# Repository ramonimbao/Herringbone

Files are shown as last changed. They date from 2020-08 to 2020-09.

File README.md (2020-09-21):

# Herringbone

### Through-hole 75% Keyboard



### Partslist
 |Count|Part|
 |-|-|
 |1|ATmega32A 40 pin DIP|
 |1|40 pin DIP socket|
 |1|HRO-TYPE-C-M-12|
 |1|500 mA polyfuse|
 |2|6mm momentary push buttons|
 |1|16 MHz quartz crystal|
 |1|10 uF electrolytic capacitor|
 |2|100 nF ceramic disk capacitor|
 |2|22 pF ceramic disk capacitor|
 |2|68 Ω resistor|
 |2|1.5 kΩ resistor|
 |2|5.1 kΩ resistor|
 |2|3.6 V zener diode|
 |84|universal switching diode|

This design may be freely produced, modified, and manufactured for **PERSONAL USE ONLY** and may not be reproduced in physical form for public sale.

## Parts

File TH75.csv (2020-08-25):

Source: | D:\Projects\KiCad\TH75\TH75.sch
Date: | 31 May 2020 2:26:34 PM
Tool: | Eeschema (5.1.6)-1
Generator: | D:\Applications\KiCad5\bin\scripting\plugins/bom_csv_grouped_by_value.py
Component Count: | 209
Individual Components:
Item | Qty | Reference(s) | Value | LibPart | Footprint | Datasheet
 |  | C1 | 22pF | Device:C_Small | Capacitor_THT:C_Disc_D3.0mm_W1.6mm_P2.50mm | ~
 |  | C2 | 22pF | Device:C_Small | Capacitor_THT:C_Disc_D3.0mm_W1.6mm_P2.50mm | ~
 |  | C3 | 100nF | Device:C_Small | Capacitor_THT:C_Disc_D4.3mm_W1.9mm_P5.00mm | ~
 |  | C4 | 100nF | Device:C_Small | Capacitor_THT:C_Disc_D4.3mm_W1.9mm_P5.00mm | ~
 |  | C5 | 10uF | Device:C_Small | Capacitor_THT:CP_Radial_D4.0mm_P1.50mm | ~
 |  | D1 | LED | Device:LED | LED_THT:LED_D3.0mm | ~
 |  | D2 | 3.6V | Device:D_Zener_Small | Diode_THT:D_DO-34_SOD68_P7.62mm_Horizontal | ~
 |  | D3 | 3.6V | Device:D_Zener_Small | Diode_THT:D_DO-34_SOD68_P7.62mm_Horizontal | ~
 |  | D4 | 1N4148 | Device:D_Small | Diode_THT:D_DO-34_SOD68_P7.62mm_Horizontal | ~
 |  | D5 | 1N4148 | Device:D_Small | Diode_THT:D_DO-34_SOD68_P7.62mm_Horizontal | ~
 |  | D6 | 1N4148 | Device:D_Small | Diode_THT:D_DO-34_SOD68_P7.62mm_Horizontal | ~
 |  | D7 | 1N4148 | Device:D_Small | Diode_THT:D_DO-34_SOD68_P7.62mm_Horizontal | ~
 |  | D8 | 1N4148 | Device:D_Small | Diode_THT:D_DO-34_SOD68_P7.62mm_Horizontal | ~
 |  | D9 | 1N4148 | Device:D_Small | Diode_THT:D_DO-34_SOD68_P7.62mm_Horizontal | ~
 |  | D10 | 1N4148 | Device:D_Small | Diode_THT:D_DO-34_SOD68_P7.62mm_Horizontal | ~
 |  | D11 | 1N4148 | Device:D_Small | Diode_THT:D_DO-34_SOD68_P7.62mm_Horizontal | ~
 |  | D12 | 1N4148 | Device:D_Small | Diode_THT:D_DO-34_SOD68_P7.62mm_Horizontal | ~
 |  | D13 | 1N4148 | Device:D_Small | Diode_THT:D_DO-34_SOD68_P7.62mm_Horizontal | ~
 |  | D14 | 1N4148 | Device:D_Small | Diode_THT:D_DO-34_SOD68_P7.62mm_Horizontal | ~
 |  | D15 | 1N4148 | Device:D_Small | Diode_THT:D_DO-34_SOD68_P7.62mm_Horizontal | ~
 |  | D16 | 1N4148 | Device:D_Small | Diode_THT:D_DO-34_SOD68_P7.62mm_Horizontal | ~
 |  | D17 | 1N4148 | Device:D_Small | Diode_THT:D_DO-34_SOD68_P7.62mm_Horizontal | ~
 |  | D18 | 1N4148 | Device:D_Small | Diode_THT:D_DO-34_SOD68_P7.62mm_Horizontal | ~
 |  | D19 | 1N4148 | Device:D_Small | Diode_THT:D_DO-34_SOD68_P7.62mm_Horizontal | ~
 |  | D20 | 1N4148 | Device:D_Small | Diode_THT:D_DO-34_SOD68_P7.62mm_Horizontal | ~
 |  | D21 | 1N4148 | Device:D_Small | Diode_THT:D_DO-34_SOD68_P7.62mm_Horizontal | ~
 |  | D22 | 1N4148 | Device:D_Small | Diode_THT:D_DO-34_SOD68_P7.62mm_Horizontal | ~
 |  | D23 | 1N4148 | Device:D_Small | Diode_THT:D_DO-34_SOD68_P7.62mm_Horizontal | ~
 |  | D24 | 1N4148 | Device:D_Small | Diode_THT:D_DO-34_SOD68_P7.62mm_Horizontal | ~
 |  | D25 | 1N4148 | Device:D_Small | Diode_THT:D_DO-34_SOD68_P7.62mm_Horizontal | ~
 |  | D26 | 1N4148 | Device:D_Small | Diode_THT:D_DO-34_SOD68_P7.62mm_Horizontal | ~
 |  | D27 | 1N4148 | Device:D_Small | Diode_THT:D_DO-34_SOD68_P7.62mm_Horizontal | ~
 |  | D28 | 1N4148 | Device:D_Small | Diode_THT:D_DO-34_SOD68_P7.62mm_Horizontal | ~
 |  | D29 | 1N4148 | Device:D_Small | Diode_THT:D_DO-34_SOD68_P7.62mm_Horizontal | ~
 |  | D30 | 1N4148 | Device:D_Small | Diode_THT:D_DO-34_SOD68_P7.62mm_Horizontal | ~
 |  | D31 | 1N4148 | Device:D_Small | Diode_THT:D_DO-34_SOD68_P7.62mm_Horizontal | ~
 |  | D32 | 1N4148 | Device:D_Small | Diode_THT:D_DO-34_SOD68_P7.62mm_Horizontal | ~
 |  | D33 | 1N4148 | Device:D_Small | Diode_THT:D_DO-34_SOD68_P7.62mm_Horizontal | ~
 |  | D34 | 1N4148 | Device:D_Small | Diode_THT:D_DO-34_SOD68_P7.62mm_Horizontal | ~
 |  | D35 | 1N4148 | Device:D_Small | Diode_THT:D_DO-34_SOD68_P7.62mm_Horizontal | ~
 |  | D36 | 1N4148 | Device:D_Small | Diode_THT:D_DO-34_SOD68_P7.62mm_Horizontal | ~
 |  | D37 | 1N4148 | Device:D_Small | Diode_THT:D_DO-34_SOD68_P7.62mm_Horizontal | ~
 |  | D38 | 1N4148 | Device:D_Small | Diode_THT:D_DO-34_SOD68_P7.62mm_Horizontal | ~
 |  | D39 | 1N4148 | Device:D_Small | Diode_THT:D_DO-34_SOD68_P7.62mm_Horizontal | ~
 |  | D40 | 1N4148 | Device:D_Small | Diode_THT:D_DO-34_SOD68_P7.62mm_Horizontal | ~
 |  | D41 | 1N4148 | Device:D_Small | Diode_THT:D_DO-34_SOD68_P7.62mm_Horizontal | ~
 |  | D42 | 1N4148 | Device:D_Small | Diode_THT:D_DO-34_SOD68_P7.62mm_Horizontal | ~
 |  | D43 | 1N4148 | Device:D_Small | Diode_THT:D_DO-34_SOD68_P7.62mm_Horizontal | ~
 |  | D44 | 1N4148 | Device:D_Small | Diode_THT:D_DO-34_SOD68_P7.62mm_Horizontal | ~
 |  | D45 | 1N4148 | Device:D_Small | Diode_THT:D_DO-34_SOD68_P7.62mm_Horizontal | ~
 |  | D46 | 1N4148 | Device:D_Small | Diode_THT:D_DO-34_SOD68_P7.62mm_Horizontal | ~
 |  | D47 | 1N4148 | Device:D_Small | Diode_THT:D_DO-34_SOD68_P7.62mm_Horizontal | ~
 |  | D48 | 1N4148 | Device:D_Small | Diode_THT:D_DO-34_SOD68_P7.62mm_Horizontal | ~
 |  | D49 | 1N4148 | Device:D_Small | Diode_THT:D_DO-34_SOD68_P7.62mm_Horizontal | ~
 |  | D50 | 1N4148 | Device:D_Small | Diode_THT:D_DO-34_SOD68_P7.62mm_Horizontal | ~
 |  | D51 | 1N4148 | Device:D_Small | Diode_THT:D_DO-34_SOD68_P7.62mm_Horizontal | ~
 |  | D52 | 1N4148 | Device:D_Small | Diode_THT:D_DO-34_SOD68_P7.62mm_Horizontal | ~
 |  | D53 | 1N4148 | Device:D_Small | Diode_THT:D_DO-34_SOD68_P7.62mm_Horizontal | ~
 |  | D54 | 1N4148 | Device:D_Small | Diode_THT:D_DO-34_SOD68_P7.62mm_Horizontal | ~
 |  | D55 | 1N4148 | Device:D_Small | Diode_THT:D_DO-34_SOD68_P7.62mm_Horizontal | ~
 |  | D56 | 1N4148 | Device:D_Small | Diode_THT:D_DO-34_SOD68_P7.62mm_Horizontal | ~
 |  | D57 | 1N4148 | Device:D_Small | Diode_THT:D_DO-34_SOD68_P7.62mm_Horizontal | ~
 |  | D58 | 1N4148 | Device:D_Small | Diode_THT:D_DO-34_SOD68_P7.62mm_Horizontal | ~
 |  | D59 | 1N4148 | Device:D_Small | Diode_THT:D_DO-34_SOD68_P7.62mm_Horizontal | ~
 |  | D60 | 1N4148 | Device:D_Small | Diode_THT:D_DO-34_SOD68_P7.62mm_Horizontal | ~
 |  | D61 | 1N4148 | Device:D_Small | Diode_THT:D_DO-34_SOD68_P7.62mm_Horizontal | ~
 |  | D62 | 1N4148 | Device:D_Small | Diode_THT:D_DO-34_SOD68_P7.62mm_Horizontal | ~
 |  | D63 | 1N4148 | Device:D_Small | Diode_THT:D_DO-34_SOD68_P7.62mm_Horizontal | ~
 |  | D64 | 1N4148 | Device:D_Small | Diode_THT:D_DO-34_SOD68_P7.62mm_Horizontal | ~
 |  | D65 | 1N4148 | Device:D_Small | Diode_THT:D_DO-34_SOD68_P7.62mm_Horizontal | ~
 |  | D66 | 1N4148 | Device:D_Small | Diode_THT:D_DO-34_SOD68_P7.62mm_Horizontal | ~
 |  | D67 | 1N4148 | Device:D_Small | Diode_THT:D_DO-34_SOD68_P7.62mm_Horizontal | ~
 |  | D68 | 1N4148 | Device:D_Small | Diode_THT:D_DO-34_SOD68_P7.62mm_Horizontal | ~
 |  | D69 | 1N4148 | Device:D_Small | Diode_THT:D_DO-34_SOD68_P7.62mm_Horizontal | ~
 |  | D70 | 1N4148 | Device:D_Small | Diode_THT:D_DO-34_SOD68_P7.62mm_Horizontal | ~
 |  | D71 | 1N4148 | Device:D_Small | Diode_THT:D_DO-34_SOD68_P7.62mm_Horizontal | ~
 |  | D72 | 1N4148 | Device:D_Small | Diode_THT:D_DO-34_SOD68_P7.62mm_Horizontal | ~
 |  | D73 | 1N4148 | Device:D_Small | Diode_THT:D_DO-34_SOD68_P7.62mm_Horizontal | ~
 |  | D74 | 1N4148 | Device:D_Small | Diode_THT:D_DO-34_SOD68_P7.62mm_Horizontal | ~
 |  | D75 | 1N4148 | Device:D_Small | Diode_THT:D_DO-34_SOD68_P7.62mm_Horizontal | ~
 |  | D76 | 1N4148 | Device:D_Small | Diode_THT:D_DO-34_SOD68_P7.62mm_Horizontal | ~
 |  | D77 | 1N4148 | Device:D_Small | Diode_THT:D_DO-34_SOD68_P7.62mm_Horizontal | ~
 |  | D78 | 1N4148 | Device:D_Small | Diode_THT:D_DO-34_SOD68_P7.62mm_Horizontal | ~
 |  | D79 | 1N4148 | Device:D_Small | Diode_THT:D_DO-34_SOD68_P7.62mm_Horizontal | ~
 |  | D80 | 1N4148 | Device:D_Small | Diode_THT:D_DO-34_SOD68_P7.62mm_Horizontal | ~
 |  | D81 | 1N4148 | Device:D_Small | Diode_THT:D_DO-34_SOD68_P7.62mm_Horizontal | ~
 |  | D82 | 1N4148 | Device:D_Small | Diode_THT:D_DO-34_SOD68_P7.62mm_Horizontal | ~
 |  | D83 | 1N4148 | Device:D_Small | Diode_THT:D_DO-34_SOD68_P7.62mm_Horizontal | ~
 |  | D84 | 1N4148 | Device:D_Small | Diode_THT:D_DO-34_SOD68_P7.62mm_Horizontal | ~
 |  | D85 | 1N4148 | Device:D_Small | Diode_THT:D_DO-34_SOD68_P7.62mm_Horizontal | ~
 |  | D86 | 1N4148 | Device:D_Small | Diode_THT:D_DO-34_SOD68_P7.62mm_Horizontal | ~
 |  | D87 | 1N4148 | Device:D_Small | Diode_THT:D_DO-34_SOD68_P7.62mm_Horizontal | ~
 |  | F1 | 500mA | Device:Fuse | Capacitor_THT:C_Disc_D5.0mm_W2.5mm_P5.00mm | ~
 |  | G1 | HerringbonePattern | Mechanical:MountingHole | HerringbonePatterns:front-pattern | ~
 |  | H1 | M2 | Mechanical:MountingHole_Pad | MountingHole:MountingHole_2.2mm_M2_Pad_Via | ~
 |  | H2 | M2 | Mechanical:MountingHole_Pad | MountingHole:MountingHole_2.2mm_M2_Pad_Via | ~
 |  | H3 | M2 | Mechanical:MountingHole_Pad | MountingHole:MountingHole_2.2mm_M2_Pad_Via | ~
 |  | H4 | M2 | Mechanical:MountingHole_Pad | MountingHole:MountingHole_2.2mm_M2_Pad_Via | ~
 |  | H5 | M2 | Mechanical:MountingHole_Pad | MountingHole:MountingHole_2.2mm_M2_Pad_Via | ~
 |  | H6 | M2 | Mechanical:MountingHole_Pad | MountingHole:MountingHole_2.2mm_M2_Pad_Via | ~
 |  | H7 | M2 | Mechanical:MountingHole_Pad | MountingHole:MountingHole_2.2mm_M2_Pad_Via | ~
 |  | H8 | M2 | Mechanical:MountingHole_Pad | MountingHole:MountingHole_2.2mm_M2_Pad_Via | ~
 |  | H9 | M2 | Mechanical:MountingHole_Pad | MountingHole:MountingHole_2.2mm_M2_Pad_Via | ~
 |  | H10 | M2 | Mechanical:MountingHole_Pad | MountingHole:MountingHole_2.2mm_M2_Pad_Via | ~
 |  | H11 | LOGO | Mechanical:MountingHole | Ramon:Signature | ~
 |  | H12 | M2 | Mechanical:MountingHole_Pad | MountingHole:MountingHole_2.2mm_M2_Pad_Via | ~
 |  | H13 | M2 | Mechanical:MountingHole_Pad | MountingHole:MountingHole_2.2mm_M2_Pad_Via | ~
 |  | J1 | Conn_02x03_Odd_Even | Connector_Generic:Conn_02x03_Odd_Even | random-keyboard-parts:Reset_Pretty | ~
 |  | J2 | Conn_01x06 | Connector_Generic:Conn_01x06 | Connector_PinSocket_2.54mm:PinSocket_1x06_P2.54mm_Vertical | ~
 |  | MX1 | MX-NoLED | MX_Alps_Hybrid:MX-NoLED | MX_Only:MXOnly-1U-NoLED
 |  | MX2 | MX-NoLED | MX_Alps_Hybrid:MX-NoLED | MX_Only:MXOnly-1U-NoLED
 |  | MX3 | MX-NoLED | MX_Alps_Hybrid:MX-NoLED | MX_Only:MXOnly-1U-NoLED
 |  | MX4 | MX-NoLED | MX_Alps_Hybrid:MX-NoLED | MX_Only:MXOnly-1U-NoLED
 |  | MX5 | MX-NoLED | MX_Alps_Hybrid:MX-NoLED | MX_Only:MXOnly-1U-NoLED
 |  | MX6 | MX-NoLED | MX_Alps_Hybrid:MX-NoLED | MX_Only:MXOnly-1U-NoLED
 |  | MX7 | MX-NoLED | MX_Alps_Hybrid:MX-NoLED | MX_Only:MXOnly-1U-NoLED
 |  | MX8 | MX-NoLED | MX_Alps_Hybrid:MX-NoLED | MX_Only:MXOnly-1U-NoLED
 |  | MX9 | MX-NoLED | MX_Alps_Hybrid:MX-NoLED | MX_Only:MXOnly-1U-NoLED
 |  | MX10 | MX-NoLED | MX_Alps_Hybrid:MX-NoLED | MX_Only:MXOnly-1U-NoLED
 |  | MX11 | MX-NoLED | MX_Alps_Hybrid:MX-NoLED | MX_Only:MXOnly-1U-NoLED
 |  | MX12 | MX-NoLED | MX_Alps_Hybrid:MX-NoLED | MX_Only:MXOnly-1U-NoLED
 |  | MX13 | MX-NoLED | MX_Alps_Hybrid:MX-NoLED | MX_Only:MXOnly-1U-NoLED
 |  | MX14 | MX-NoLED | MX_Alps_Hybrid:MX-NoLED | MX_Only:MXOnly-1U-NoLED
 |  | MX15 | MX-NoLED | MX_Alps_Hybrid:MX-NoLED | MX_Only:MXOnly-1U-NoLED
 |  | MX16 | MX-NoLED | MX_Alps_Hybrid:MX-NoLED | MX_Only:MXOnly-1U-NoLED
 |  | MX17 | MX-NoLED | MX_Alps_Hybrid:MX-NoLED | MX_Only:MXOnly-1U-NoLED
 |  | MX18 | MX-NoLED | MX_Alps_Hybrid:MX-NoLED | MX_Only:MXOnly-1U-NoLED
 |  | MX19 | MX-NoLED | MX_Alps_Hybrid:MX-NoLED | MX_Only:MXOnly-1U-NoLED
 |  | MX20 | MX-NoLED | MX_Alps_Hybrid:MX-NoLED | MX_Only:MXOnly-1U-NoLED
 |  | MX21 | MX-NoLED | MX_Alps_Hybrid:MX-NoLED | MX_Only:MXOnly-1U-NoLED
 |  | MX22 | MX-NoLED | MX_Alps_Hybrid:MX-NoLED | MX_Only:MXOnly-1U-NoLED
 |  | MX23 | MX-NoLED | MX_Alps_Hybrid:MX-NoLED | MX_Only:MXOnly-1U-NoLED
 |  | MX24 | MX-NoLED | MX_Alps_Hybrid:MX-NoLED | MX_Only:MXOnly-1U-NoLED
 |  | MX25 | MX-NoLED | MX_Alps_Hybrid:MX-NoLED | MX_Only:MXOnly-1U-NoLED
 |  | MX26 | MX-NoLED | MX_Alps_Hybrid:MX-NoLED | MX_Only:MXOnly-1U-NoLED
 |  | MX27 | MX-NoLED | MX_Alps_Hybrid:MX-NoLED | MX_Only:MXOnly-1U-NoLED
 |  | MX28 | MX-NoLED | MX_Alps_Hybrid:MX-NoLED | MX_Only:MXOnly-1U-NoLED
 |  | MX29 | MX-NoLED | MX_Alps_Hybrid:MX-NoLED | MX_Only:MXOnly-2U-NoLED
 |  | MX30 | MX-NoLED | MX_Alps_Hybrid:MX-NoLED | MX_Only:MXOnly-1U-NoLED
 |  | MX31 | MX-NoLED | MX_Alps_Hybrid:MX-NoLED | MX_Only:MXOnly-1.5U-NoLED
 |  | MX32 | MX-NoLED | MX_Alps_Hybrid:MX-NoLED | MX_Only:MXOnly-1U-NoLED
 |  | MX33 | MX-NoLED | MX_Alps_Hybrid:MX-NoLED | MX_Only:MXOnly-1U-NoLED
 |  | MX34 | MX-NoLED | MX_Alps_Hybrid:MX-NoLED | MX_Only:MXOnly-1U-NoLED
 |  | MX35 | MX-NoLED | MX_Alps_Hybrid:MX-NoLED | MX_Only:MXOnly-1U-NoLED
 |  | MX36 | MX-NoLED | MX_Alps_Hybrid:MX-NoLED | MX_Only:MXOnly-1U-NoLED
 |  | MX37 | MX-NoLED | MX_Alps_Hybrid:MX-NoLED | MX_Only:MXOnly-1U-NoLED
 |  | MX38 | MX-NoLED | MX_Alps_Hybrid:MX-NoLED | MX_Only:MXOnly-1U-NoLED
 |  | MX39 | MX-NoLED | MX_Alps_Hybrid:MX-NoLED | MX_Only:MXOnly-1U-NoLED
 |  | MX40 | MX-NoLED | MX_Alps_Hybrid:MX-NoLED | MX_Only:MXOnly-1U-NoLED
 |  | MX41 | MX-NoLED | MX_Alps_Hybrid:MX-NoLED | MX_Only:MXOnly-1U-NoLED
 |  | MX42 | MX-NoLED | MX_Alps_Hybrid:MX-NoLED | MX_Only:MXOnly-1U-NoLED
 |  | MX43 | MX-NoLED | MX_Alps_Hybrid:MX-NoLED | MX_Only:MXOnly-1U-NoLED
 |  | MX44 | MX-NoLED | MX_Alps_Hybrid:MX-NoLED | MX_Only:MXOnly-1.5U-NoLED
 |  | MX45 | MX-NoLED | MX_Alps_Hybrid:MX-NoLED | MX_Only:MXOnly-1U-NoLED
 |  | MX46 | MX-NoLED | MX_Alps_Hybrid:MX-NoLED | MX_Only:MXOnly-1.75U-NoLED
 |  | MX47 | MX-NoLED | MX_Alps_Hybrid:MX-NoLED | MX_Only:MXOnly-1U-NoLED
 |  | MX48 | MX-NoLED | MX_Alps_Hybrid:MX-NoLED | MX_Only:MXOnly-1U-NoLED
 |  | MX49 | MX-NoLED | MX_Alps_Hybrid:MX-NoLED | MX_Only:MXOnly-1U-NoLED
 |  | MX50 | MX-NoLED | MX_Alps_Hybrid:MX-NoLED | MX_Only:MXOnly-1U-NoLED
 |  | MX51 | MX-NoLED | MX_Alps_Hybrid:MX-NoLED | MX_Only:MXOnly-1U-NoLED
 |  | MX52 | MX-NoLED | MX_Alps_Hybrid:MX-NoLED | MX_Only:MXOnly-1U-NoLED
 |  | MX53 | MX-NoLED | MX_Alps_Hybrid:MX-NoLED | MX_Only:MXOnly-1U-NoLED
 |  | MX54 | MX-NoLED | MX_Alps_Hybrid:MX-NoLED | MX_Only:MXOnly-1U-NoLED
 |  | MX55 | MX-NoLED | MX_Alps_Hybrid:MX-NoLED | MX_Only:MXOnly-1U-NoLED
 |  | MX56 | MX-NoLED | MX_Alps_Hybrid:MX-NoLED | MX_Only:MXOnly-1U-NoLED
 |  | MX57 | MX-NoLED | MX_Alps_Hybrid:MX-NoLED | MX_Only:MXOnly-1U-NoLED
 |  | MX58 | MX-NoLED | MX_Alps_Hybrid:MX-NoLED | MX_Only:MXOnly-2.25U-NoLED
 |  | MX59 | MX-NoLED | MX_Alps_Hybrid:MX-NoLED | MX_Only:MXOnly-1U-NoLED
 |  | MX60 | MX-NoLED | MX_Alps_Hybrid:MX-NoLED | MX_Only:MXOnly-1.25U-NoLED
 |  | MX61 | MX-NoLED | MX_Alps_Hybrid:MX-NoLED | MX_Only:MXOnly-2.25U-NoLED
 |  | MX62 | MX-NoLED | MX_Alps_Hybrid:MX-NoLED | MX_Only:MXOnly-1U-NoLED
 |  | MX63 | MX-NoLED | MX_Alps_Hybrid:MX-NoLED | MX_Only:MXOnly-1U-NoLED
 |  | MX64 | MX-NoLED | MX_Alps_Hybrid:MX-NoLED | MX_Only:MXOnly-1U-NoLED
 |  | MX65 | MX-NoLED | MX_Alps_Hybrid:MX-NoLED | MX_Only:MXOnly-1U-NoLED
 |  | MX66 | MX-NoLED | MX_Alps_Hybrid:MX-NoLED | MX_Only:MXOnly-1U-NoLED
 |  | MX67 | MX-NoLED | MX_Alps_Hybrid:MX-NoLED | MX_Only:MXOnly-1U-NoLED
 |  | MX68 | MX-NoLED | MX_Alps_Hybrid:MX-NoLED | MX_Only:MXOnly-1U-NoLED
 |  | MX69 | MX-NoLED | MX_Alps_Hybrid:MX-NoLED | MX_Only:MXOnly-1U-NoLED
 |  | MX70 | MX-NoLED | MX_Alps_Hybrid:MX-NoLED | MX_Only:MXOnly-1U-NoLED
 |  | MX71 | MX-NoLED | MX_Alps_Hybrid:MX-NoLED | MX_Only:MXOnly-1U-NoLED
 |  | MX72 | MX-NoLED | MX_Alps_Hybrid:MX-NoLED | MX_Only:MXOnly-1.75U-NoLED
 |  | MX73 | MX-NoLED | MX_Alps_Hybrid:MX-NoLED | MX_Only:MXOnly-1U-NoLED
 |  | MX74 | MX-NoLED | MX_Alps_Hybrid:MX-NoLED | MX_Only:MXOnly-1U-NoLED
 |  | MX75 | MX-NoLED | MX_Alps_Hybrid:MX-NoLED | MX_Only:MXOnly-1.25U-NoLED
 |  | MX76 | MX-NoLED | MX_Alps_Hybrid:MX-NoLED | MX_Only:MXOnly-1.25U-NoLED
 |  | MX77 | MX-NoLED | MX_Alps_Hybrid:MX-NoLED | MX_Only:MXOnly-1.25U-NoLED
 |  | MX78 | MX-NoLED | MX_Alps_Hybrid:MX-NoLED | MX_Only:MXOnly-6.25U-ReversedStabilizers-NoLED
 |  | MX79 | MX-NoLED | MX_Alps_Hybrid:MX-NoLED | MX_Only:MXOnly-1.5U-NoLED
 |  | MX80 | MX-NoLED | MX_Alps_Hybrid:MX-NoLED | MX_Only:MXOnly-1.5U-NoLED
 |  | MX81 | MX-NoLED | MX_Alps_Hybrid:MX-NoLED | MX_Only:MXOnly-1U-NoLED
 |  | MX82 | MX-NoLED | MX_Alps_Hybrid:MX-NoLED | MX_Only:MXOnly-1U-NoLED
 |  | MX83 | MX-NoLED | MX_Alps_Hybrid:MX-NoLED | MX_Only:MXOnly-1U-NoLED
 |  | MX84 | MX-NoLED | MX_Alps_Hybrid:MX-NoLED | MX_Only:MXOnly-1U-NoLED
 |  | MX85 | MX-NoLED | MX_Alps_Hybrid:MX-NoLED | MX_Only:MXOnly-ISO-ROTATED-ReversedStabilizers-NoLED
 |  | MX86 | MX-NoLED | MX_Alps_Hybrid:MX-NoLED | MX_Only:MXOnly-1U-NoLED
 |  | MX87 | MX-NoLED | MX_Alps_Hybrid:MX-NoLED | MX_Only:MXOnly-1U-NoLED
 |  | MX88 | MX-NoLED | MX_Alps_Hybrid:MX-NoLED | MX_Only:MXOnly-1.25U-NoLED
 |  | MX89 | MX-NoLED | MX_Alps_Hybrid:MX-NoLED | MX_Only:MXOnly-1U-NoLED
 |  | R1 | 1.5k | Device:R_Small | Resistor_THT:R_Axial_DIN0204_L3.6mm_D1.6mm_P5.08mm_Horizontal | ~
 |  | R2 | 1.5k | Device:R_Small | Resistor_THT:R_Axial_DIN0204_L3.6mm_D1.6mm_P5.08mm_Horizontal | ~
 |  | R3 | 75 | Device:R_Small | Resistor_THT:R_Axial_DIN0204_L3.6mm_D1.6mm_P5.08mm_Horizontal | ~
 |  | R4 | 75 | Device:R_Small | Resistor_THT:R_Axial_DIN0204_L3.6mm_D1.6mm_P5.08mm_Horizontal | ~
 |  | R5 | 5.1k | Device:R_Small | Resistor_THT:R_Axial_DIN0204_L3.6mm_D1.6mm_P5.08mm_Horizontal | ~
 |  | R6 | 5.1k | Device:R_Small | Resistor_THT:R_Axial_DIN0204_L3.6mm_D1.6mm_P5.08mm_Horizontal | ~
 |  | SW1 | SW_Push | Switch:SW_Push | Button_Switch_THT:SW_PUSH_6mm | ~
 |  | SW2 | SW_Push | Switch:SW_Push | Button_Switch_THT:SW_PUSH_6mm | ~
 |  | U1 | ATmega32A-PU | TH75-rescue:ATmega32A-PU-MCU_Microchip_ATmega | Package_DIP:DIP-40_W15.24mm_Socket | http://ww1.microchip.com/downloads/en/DeviceDoc/atmel-8155-8-bit-microcontroller-avr-atmega32a_datasheet.pdf
 |  | USB1 | HRO-USB-SPACER | Type-C:HRO-USB-SPACER | Type-C:HRO-TYPE-C-31-M-12-USB-Spacer
 |  | Y1 | 16MHz | Device:Crystal | Crystal:Crystal_HC49-4H_Vertical | ~
Collated Components:
Item | Qty | Reference(s) | Value | LibPart | Footprint | Datasheet
1 | 2 | C1, C2 | 22pF | Device:C_Small | Capacitor_THT:C_Disc_D3.0mm_W1.6mm_P2.50mm | ~
2 | 2 | C3, C4 | 100nF | Device:C_Small | Capacitor_THT:C_Disc_D4.3mm_W1.9mm_P5.00mm | ~
3 | 1 | C5 | 10uF | Device:C_Small | Capacitor_THT:CP_Radial_D4.0mm_P1.50mm | ~
4 | 1 | D1 | LED | Device:LED | LED_THT:LED_D3.0mm | ~
5 | 2 | D2, D3 | 3.6V | Device:D_Zener_Small | Diode_THT:D_DO-34_SOD68_P7.62mm_Horizontal | ~
6 | 84 | D4, D5, D6, D7, D8, D9, D10, D11, D12, D13, D14, D15, D16, D17, D18, D19, D20, D21, D22, D23, D24, D25, D26, D27, D28, D29, D30, D31, D32, D33, D34, D35, D36, D37, D38, D39, D40, D41, D42, D43, D44, D45, D46, D47, D48, D49, D50, D51, D52, D53, D54, D55, D56, D57, D58, D59, D60, D61, D62, D63, D64, D65, D66, D67, D68, D69, D70, D71, D72, D73, D74, D75, D76, D77, D78, D79, D80, D81, D82, D83, D84, D85, D86, D87 | 1N4148 | Device:D_Small | Diode_THT:D_DO-34_SOD68_P7.62mm_Horizontal | ~
7 | 1 | F1 | 500mA | Device:Fuse | Capacitor_THT:C_Disc_D5.0mm_W2.5mm_P5.00mm | ~
11 | 1 | J1 | Conn_02x03_Odd_Even | Connector_Generic:Conn_02x03_Odd_Even | random-keyboard-parts:Reset_Pretty | ~
21 | 2 | R1, R2 | 1.5k | Device:R_Small | Resistor_THT:R_Axial_DIN0204_L3.6mm_D1.6mm_P5.08mm_Horizontal | ~
22 | 2 | R3, R4 | 75 | Device:R_Small | Resistor_THT:R_Axial_DIN0204_L3.6mm_D1.6mm_P5.08mm_Horizontal | ~
23 | 2 | R5, R6 | 5.1k | Device:R_Small | Resistor_THT:R_Axial_DIN0204_L3.6mm_D1.6mm_P5.08mm_Horizontal | ~
24 | 2 | SW1, SW2 | SW_Push | Switch:SW_Push | Button_Switch_THT:SW_PUSH_6mm | ~
25 | 1 | U1 | ATmega32A-PU | TH75-rescue:ATmega32A-PU-MCU_Microchip_ATmega | Package_DIP:DIP-40_W15.24mm_Socket | http://ww1.microchip.com/downloads/en/DeviceDoc/atmel-8155-8-bit-microcontroller-avr-atmega32a_datasheet.pdf
26 | 1 | USB1 | HRO-USB-SPACER | Type-C:HRO-USB-SPACER | Type-C:HRO-TYPE-C-31-M-12-USB-Spacer
27 | 1 | Y1 | 16MHz | Device:Crystal | Crystal:Crystal_HC49-4H_Vertical | ~

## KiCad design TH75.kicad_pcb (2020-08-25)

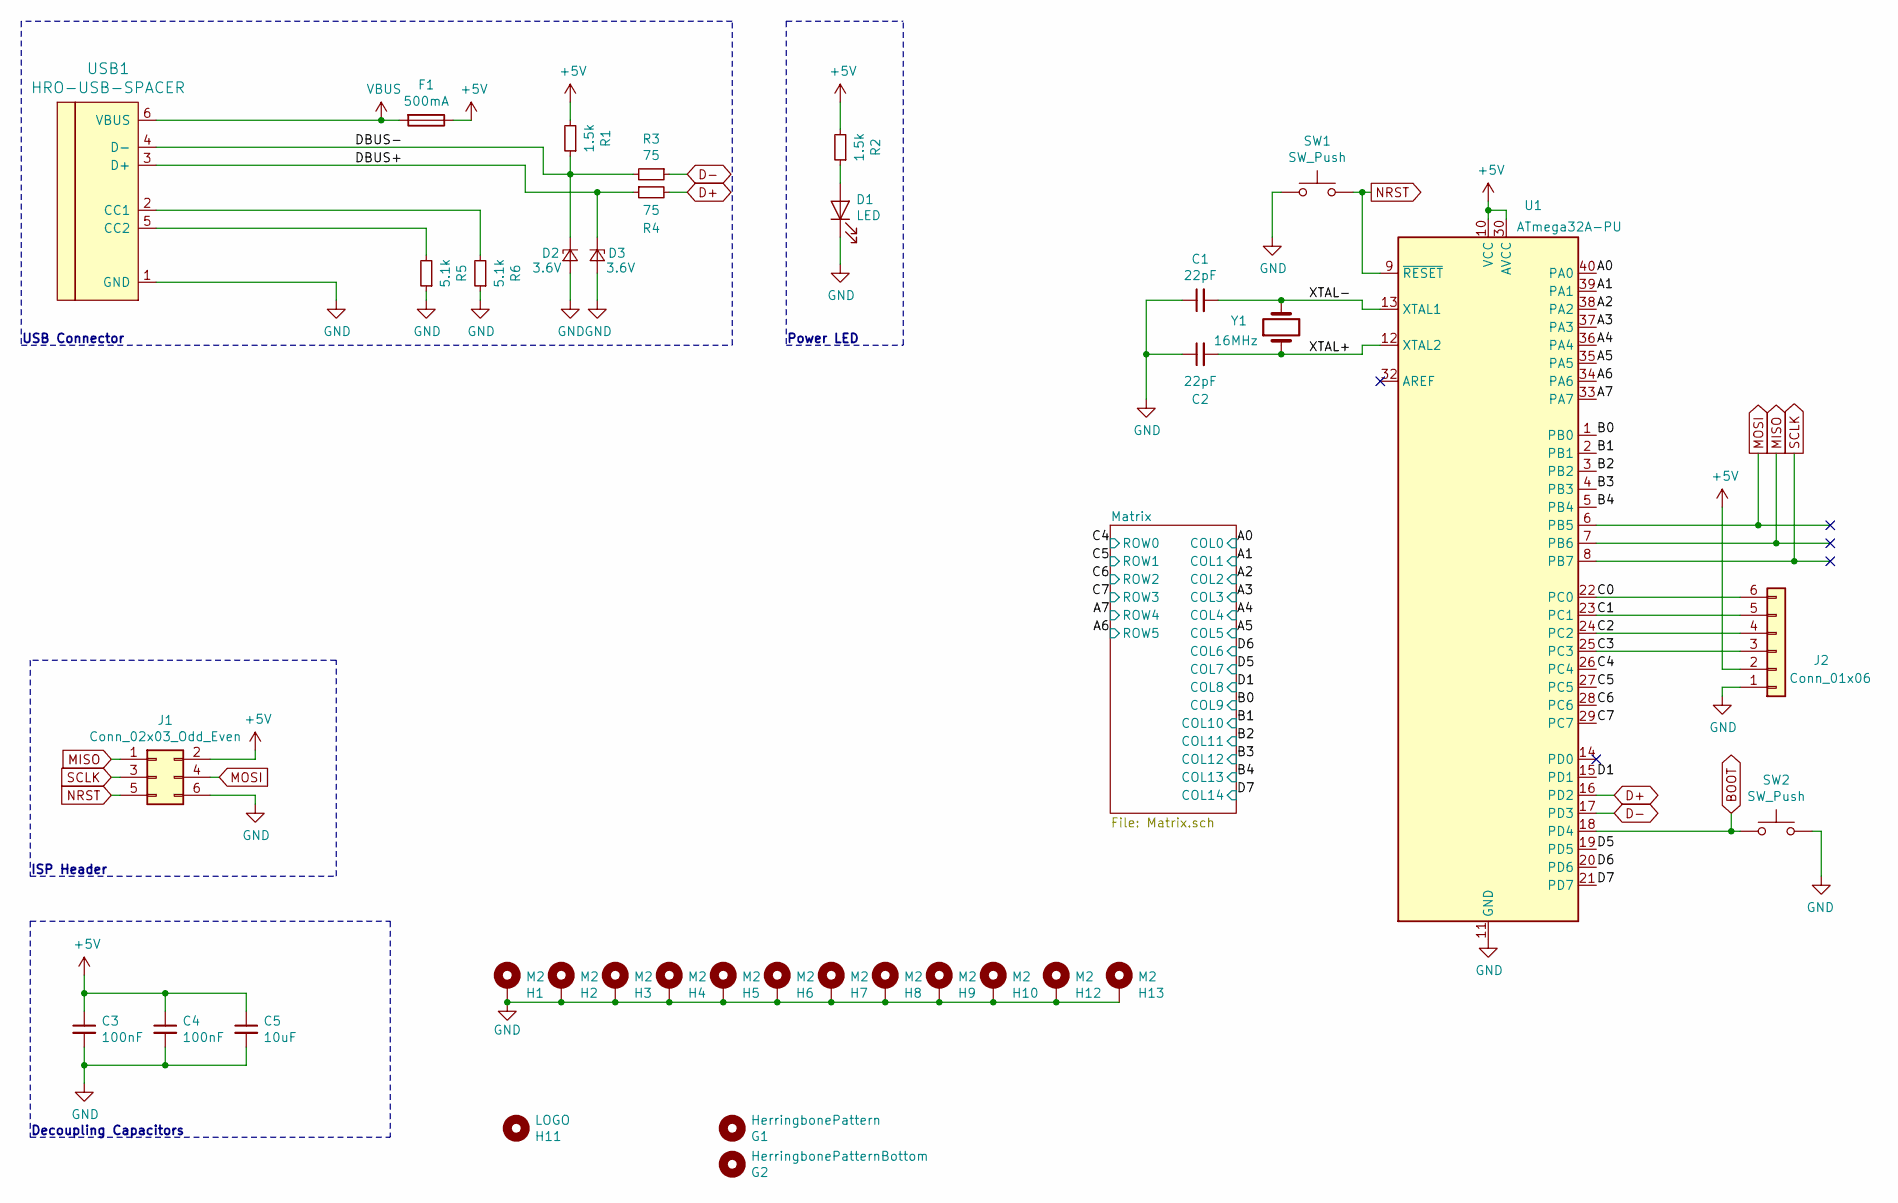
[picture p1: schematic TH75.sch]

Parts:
C1, C2: 22pF; C_Disc_D3.0mm_W1.6mm_P2.50mm
C3, C4: 100nF; C_Disc_D4.3mm_W1.9mm_P5.00mm
C5: 10uF; CP_Radial_D4.0mm_P1.50mm
D1: LED; LED_D3.0mm
D2, D3: 3.6V; D_DO-34_SOD68_P7.62mm_Horizontal
F1: 500mA; C_Disc_D5.0mm_W2.5mm_P5.00mm
G1: HerringbonePattern; front-pattern
G2: HerringbonePatternBottom; main-bottom-pattern
H1, H2, H3, H4, H5, H6, H7, H8, H9, H10, H12, H13: M2; MountingHole_2.2mm_M2_Pad_Via
H11: LOGO; Signature
J1: Conn_02x03_Odd_Even; Reset_Pretty
J2: Conn_01x06; PinSocket_1x06_P2.54mm_Vertical
R1, R2: 1.5k; R_Axial_DIN0204_L3.6mm_D1.6mm_P5.08mm_Horizontal
R3, R4: 75; R_Axial_DIN0204_L3.6mm_D1.6mm_P5.08mm_Horizontal
R5, R6: 5.1k; R_Axial_DIN0204_L3.6mm_D1.6mm_P5.08mm_Horizontal
SW1, SW2: SW_Push; SW_PUSH_6mm
U1: ATmega32A-PU; DIP-40_W15.24mm_Socket
USB1: HRO-USB-SPACER; HRO-TYPE-C-31-M-12-USB-Spacer
Y1: 16MHz; Crystal_HC49-4H_Vertical

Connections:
+5V: C3.1, C4.1, C5.1, F1.1, J1.2, J2.2, R1.2, R2.2, U1.10 (VCC), U1.30 (AVCC)
/A0: U1.40 (PA0); also elsewhere on the board
/A1: U1.39 (PA1); also elsewhere on the board
/A2: U1.38 (PA2); also elsewhere on the board
/A3: U1.37 (PA3); also elsewhere on the board
/A4: U1.36 (PA4); also elsewhere on the board
/A5: U1.35 (PA5); also elsewhere on the board
/A6: U1.34 (PA6); also elsewhere on the board
/A7: U1.33 (PA7); also elsewhere on the board
/B0: U1.1 (PB0); also elsewhere on the board
/B1: U1.2 (PB1); also elsewhere on the board
/B2: U1.3 (PB2); also elsewhere on the board
/B3: U1.4 (PB3); also elsewhere on the board
/B4: U1.5 (PB4); also elsewhere on the board
/C0: J2.6, U1.22 (PC0)
/C1: J2.5, U1.23 (PC1)
/C2: J2.4, U1.24 (PC2)
/C3: J2.3, U1.25 (PC3)
/C4: U1.26 (PC4); also elsewhere on the board
/C5: U1.27 (PC5); also elsewhere on the board
/C6: U1.28 (PC6); also elsewhere on the board
/C7: U1.29 (PC7); also elsewhere on the board
/D1: U1.15 (PD1); also elsewhere on the board
/D5: U1.19 (PD5); also elsewhere on the board
/D6: U1.20 (PD6); also elsewhere on the board
/D7: U1.21 (PD7); also elsewhere on the board
/DBUS+: D3.1 (K), R4.1, USB1.3 (D+)
/DBUS-: D2.1 (K), R1.1, R3.2, USB1.4 (D-)
/XTAL+: C2.2, U1.12 (XTAL2), Y1.1
/XTAL-: C1.2, U1.13 (XTAL1), Y1.2
BOOT: SW2.2, U1.18 (PD4)
D+: R4.2, U1.16 (PD2)
D-: R3.1, U1.17 (PD3)
GND: C1.1, C2.1, C3.2, C4.2, C5.2, D1.1 (K), D2.2 (A), D3.2 (A), H1.1, H2.1, H3.1, H4.1, H5.1, H6.1, H7.1, H8.1, H9.1, H10.1, H12.1, H13.1, J1.6, J2.1, R5.1, R6.1, SW1.1, SW2.1, U1.11 (GND), U1.31 (GND), USB1.1 (GND)
MISO: J1.1, U1.7 (PB6)
MOSI: J1.4, U1.6 (PB5)
NRST: J1.5, SW1.2, U1.9 (~RESET)
unnamed: D1.2 (A), R2.1
unnamed: R5.2, USB1.5 (CC2)
unnamed: R6.2, USB1.2 (CC1)
SCLK: J1.3, U1.8 (PB7)
VBUS: F1.2, USB1.6 (VBUS)

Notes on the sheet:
USB Connector
ISP Header
Decoupling Capacitors
Power LED

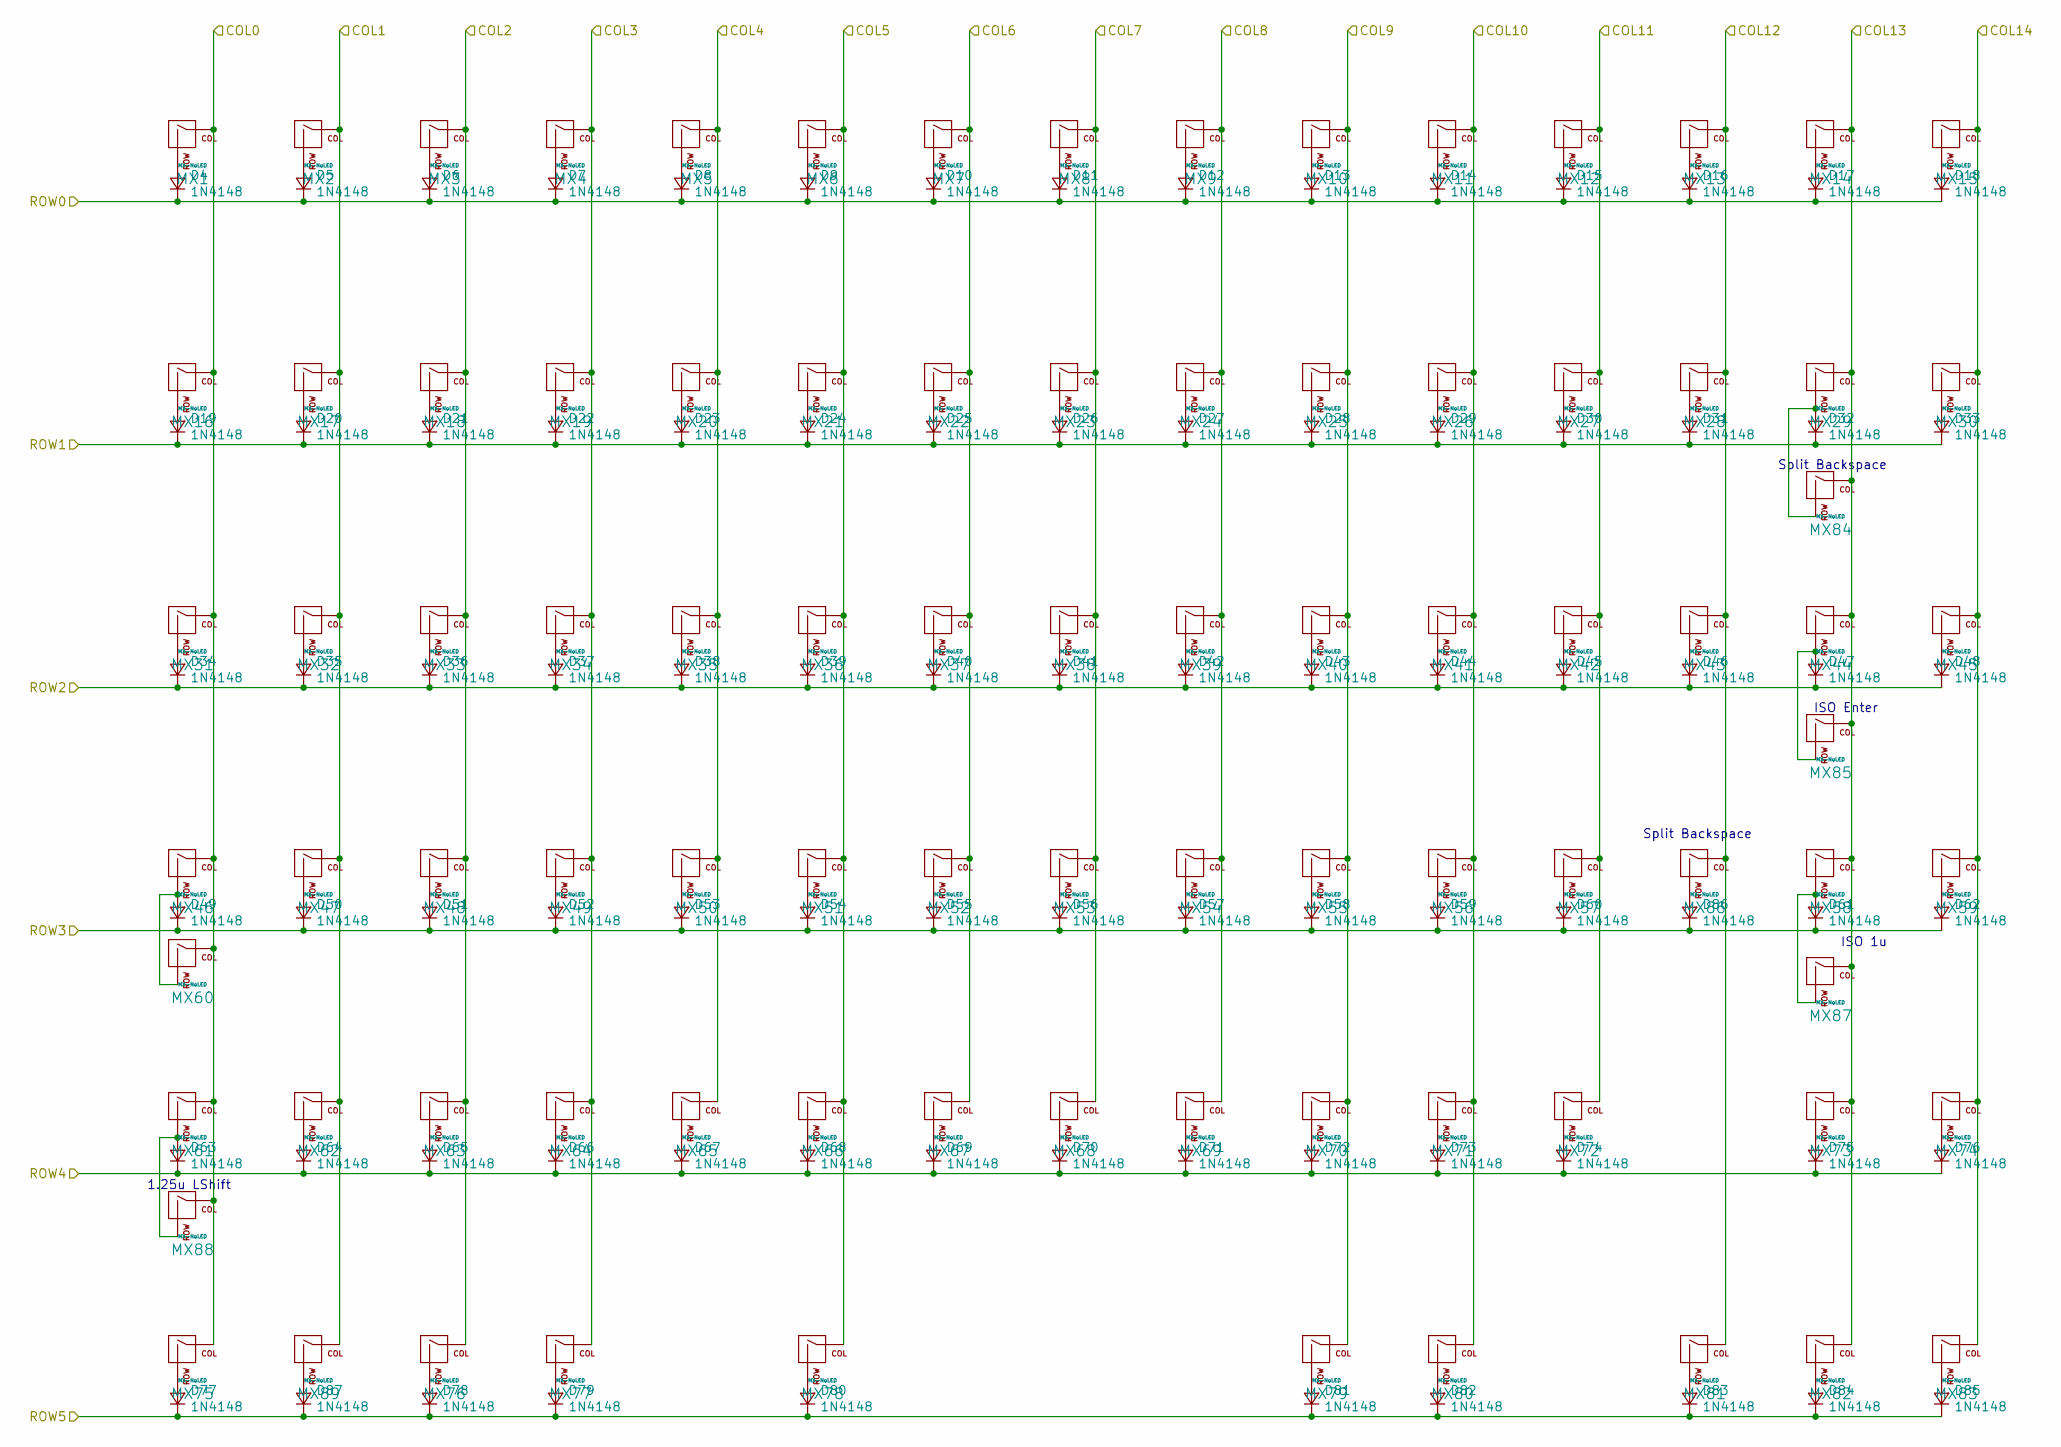
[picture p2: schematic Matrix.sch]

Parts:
D4, D5, D6, D7, D8, D9, D10, D11, D12, D13, D14, D15, D16, D17, D18, D19, D20, D21, D22, D23, D24, D25, D26, D27, D28, D29, D30, D31, D32, D33, D34, D35, D36, D37, D38, D39, D40, D41, D42, D43, D44, D45, D46, D47, D48, D49, D50, D51, D52, D53, D54, D55, D56, D57, D58, D59, D60, D61, D62, D63, D64, D65, D66, D67, D68, D69, D70, D71, D72, D73, D74, D75, D76, D77, D78, D79, D80, D81, D82, D83, D84, D85, D86, D87: 1N4148; D_DO-34_SOD68_P7.62mm_Horizontal
MX1, MX2, MX3, MX4, MX5, MX6, MX7, MX8, MX9, MX10, MX11, MX12, MX13, MX14, MX15, MX16, MX17, MX18, MX19, MX20, MX21, MX22, MX23, MX24, MX25, MX26, MX27, MX28, MX30, MX32, MX33, MX34, MX35, MX36, MX37, MX38, MX39, MX40, MX41, MX42, MX43, MX45, MX47, MX48, MX49, MX50, MX51, MX52, MX53, MX54, MX55, MX56, MX57, MX59, MX62, MX63, MX64, MX65, MX66, MX67, MX68, MX69, MX70, MX71, MX73, MX74, MX81, MX82, MX83, MX84, MX86, MX87, MX89: MX-NoLED; MXOnly-1U-NoLED
MX29: MX-NoLED; MXOnly-2U-NoLED
MX31, MX44, MX79, MX80: MX-NoLED; MXOnly-1.5U-NoLED
MX46, MX72: MX-NoLED; MXOnly-1.75U-NoLED
MX58, MX61: MX-NoLED; MXOnly-2.25U-NoLED
MX60, MX75, MX76, MX77, MX88: MX-NoLED; MXOnly-1.25U-NoLED
MX78: MX-NoLED; MXOnly-6.25U-ReversedStabilizers-NoLED
MX85: MX-NoLED; MXOnly-ISO-ROTATED-ReversedStabilizers-NoLED

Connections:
/A0: MX1.1 (COL), MX16.1 (COL), MX31.1 (COL), MX46.1 (COL), MX60.1 (COL), MX61.1 (COL), MX75.1 (COL), MX88.1 (COL); also elsewhere on the board
/A1: MX2.1 (COL), MX17.1 (COL), MX32.1 (COL), MX47.1 (COL), MX62.1 (COL), MX89.1 (COL); also elsewhere on the board
/A2: MX3.1 (COL), MX18.1 (COL), MX33.1 (COL), MX48.1 (COL), MX63.1 (COL), MX76.1 (COL); also elsewhere on the board
/A3: MX4.1 (COL), MX19.1 (COL), MX34.1 (COL), MX49.1 (COL), MX64.1 (COL), MX77.1 (COL); also elsewhere on the board
/A4: MX5.1 (COL), MX20.1 (COL), MX35.1 (COL), MX50.1 (COL), MX65.1 (COL); also elsewhere on the board
/A5: MX6.1 (COL), MX21.1 (COL), MX36.1 (COL), MX51.1 (COL), MX66.1 (COL), MX78.1 (COL); also elsewhere on the board
/A6: D77.1 (K), D78.1 (K), D79.1 (K), D80.1 (K), D81.1 (K), D82.1 (K), D83.1 (K), D84.1 (K), D85.1 (K), D87.1 (K); also elsewhere on the board
/A7: D63.1 (K), D64.1 (K), D65.1 (K), D66.1 (K), D67.1 (K), D68.1 (K), D69.1 (K), D70.1 (K), D71.1 (K), D72.1 (K), D73.1 (K), D74.1 (K), D75.1 (K), D76.1 (K); also elsewhere on the board
/B0: MX10.1 (COL), MX25.1 (COL), MX40.1 (COL), MX55.1 (COL), MX70.1 (COL), MX79.1 (COL); also elsewhere on the board
/B1: MX11.1 (COL), MX26.1 (COL), MX41.1 (COL), MX56.1 (COL), MX71.1 (COL), MX80.1 (COL); also elsewhere on the board
/B2: MX12.1 (COL), MX27.1 (COL), MX42.1 (COL), MX57.1 (COL), MX72.1 (COL); also elsewhere on the board
/B3: MX13.1 (COL), MX28.1 (COL), MX43.1 (COL), MX81.1 (COL), MX86.1 (COL); also elsewhere on the board
/B4: MX14.1 (COL), MX29.1 (COL), MX44.1 (COL), MX58.1 (COL), MX73.1 (COL), MX82.1 (COL), MX84.1 (COL), MX85.1 (COL), MX87.1 (COL); also elsewhere on the board
/C4: D4.1 (K), D5.1 (K), D6.1 (K), D7.1 (K), D8.1 (K), D9.1 (K), D10.1 (K), D11.1 (K), D12.1 (K), D13.1 (K), D14.1 (K), D15.1 (K), D16.1 (K), D17.1 (K), D18.1 (K); also elsewhere on the board
/C5: D19.1 (K), D20.1 (K), D21.1 (K), D22.1 (K), D23.1 (K), D24.1 (K), D25.1 (K), D26.1 (K), D27.1 (K), D28.1 (K), D29.1 (K), D30.1 (K), D31.1 (K), D32.1 (K), D33.1 (K); also elsewhere on the board
/C6: D34.1 (K), D35.1 (K), D36.1 (K), D37.1 (K), D38.1 (K), D39.1 (K), D40.1 (K), D41.1 (K), D42.1 (K), D43.1 (K), D44.1 (K), D45.1 (K), D46.1 (K), D47.1 (K), D48.1 (K); also elsewhere on the board
/C7: D49.1 (K), D50.1 (K), D51.1 (K), D52.1 (K), D53.1 (K), D54.1 (K), D55.1 (K), D56.1 (K), D57.1 (K), D58.1 (K), D59.1 (K), D60.1 (K), D61.1 (K), D62.1 (K), D86.1 (K); also elsewhere on the board
/D1: MX9.1 (COL), MX24.1 (COL), MX39.1 (COL), MX54.1 (COL), MX69.1 (COL); also elsewhere on the board
/D5: MX8.1 (COL), MX23.1 (COL), MX38.1 (COL), MX53.1 (COL), MX68.1 (COL); also elsewhere on the board
/D6: MX7.1 (COL), MX22.1 (COL), MX37.1 (COL), MX52.1 (COL), MX67.1 (COL); also elsewhere on the board
/D7: MX15.1 (COL), MX30.1 (COL), MX45.1 (COL), MX59.1 (COL), MX74.1 (COL), MX83.1 (COL); also elsewhere on the board
unnamed: D4.2 (A), MX1.2 (ROW)
unnamed: D5.2 (A), MX2.2 (ROW)
unnamed: D6.2 (A), MX3.2 (ROW)
unnamed: D7.2 (A), MX4.2 (ROW)
unnamed: D8.2 (A), MX5.2 (ROW)
unnamed: D9.2 (A), MX6.2 (ROW)
unnamed: D10.2 (A), MX7.2 (ROW)
unnamed: D11.2 (A), MX8.2 (ROW)
unnamed: D12.2 (A), MX9.2 (ROW)
unnamed: D13.2 (A), MX10.2 (ROW)
unnamed: D14.2 (A), MX11.2 (ROW)
unnamed: D15.2 (A), MX12.2 (ROW)
unnamed: D16.2 (A), MX13.2 (ROW)
unnamed: D17.2 (A), MX14.2 (ROW)
unnamed: D18.2 (A), MX15.2 (ROW)
unnamed: D19.2 (A), MX16.2 (ROW)
unnamed: D20.2 (A), MX17.2 (ROW)
unnamed: D21.2 (A), MX18.2 (ROW)
unnamed: D22.2 (A), MX19.2 (ROW)
unnamed: D23.2 (A), MX20.2 (ROW)
unnamed: D24.2 (A), MX21.2 (ROW)
unnamed: D25.2 (A), MX22.2 (ROW)
unnamed: D26.2 (A), MX23.2 (ROW)
unnamed: D27.2 (A), MX24.2 (ROW)
unnamed: D28.2 (A), MX25.2 (ROW)
unnamed: D29.2 (A), MX26.2 (ROW)
unnamed: D30.2 (A), MX27.2 (ROW)
unnamed: D31.2 (A), MX28.2 (ROW)
unnamed: D32.2 (A), MX29.2 (ROW), MX84.2 (ROW)
unnamed: D33.2 (A), MX30.2 (ROW)
unnamed: D34.2 (A), MX31.2 (ROW)
unnamed: D35.2 (A), MX32.2 (ROW)
unnamed: D36.2 (A), MX33.2 (ROW)
unnamed: D37.2 (A), MX34.2 (ROW)
unnamed: D38.2 (A), MX35.2 (ROW)
unnamed: D39.2 (A), MX36.2 (ROW)
unnamed: D40.2 (A), MX37.2 (ROW)
unnamed: D41.2 (A), MX38.2 (ROW)
unnamed: D42.2 (A), MX39.2 (ROW)
unnamed: D43.2 (A), MX40.2 (ROW)
unnamed: D44.2 (A), MX41.2 (ROW)
unnamed: D45.2 (A), MX42.2 (ROW)
unnamed: D46.2 (A), MX43.2 (ROW)
unnamed: D47.2 (A), MX44.2 (ROW), MX85.2 (ROW)
unnamed: D48.2 (A), MX45.2 (ROW)
unnamed: D49.2 (A), MX46.2 (ROW), MX60.2 (ROW)
unnamed: D50.2 (A), MX47.2 (ROW)
unnamed: D51.2 (A), MX48.2 (ROW)
unnamed: D52.2 (A), MX49.2 (ROW)
unnamed: D53.2 (A), MX50.2 (ROW)
unnamed: D54.2 (A), MX51.2 (ROW)
unnamed: D55.2 (A), MX52.2 (ROW)
unnamed: D56.2 (A), MX53.2 (ROW)
unnamed: D57.2 (A), MX54.2 (ROW)
unnamed: D58.2 (A), MX55.2 (ROW)
unnamed: D59.2 (A), MX56.2 (ROW)
unnamed: D60.2 (A), MX57.2 (ROW)
unnamed: D61.2 (A), MX58.2 (ROW), MX87.2 (ROW)
unnamed: D62.2 (A), MX59.2 (ROW)
unnamed: D63.2 (A), MX61.2 (ROW), MX88.2 (ROW)
unnamed: D64.2 (A), MX62.2 (ROW)
unnamed: D65.2 (A), MX63.2 (ROW)
unnamed: D66.2 (A), MX64.2 (ROW)
unnamed: D67.2 (A), MX65.2 (ROW)
unnamed: D68.2 (A), MX66.2 (ROW)
unnamed: D69.2 (A), MX67.2 (ROW)
unnamed: D70.2 (A), MX68.2 (ROW)
unnamed: D71.2 (A), MX69.2 (ROW)
unnamed: D72.2 (A), MX70.2 (ROW)
unnamed: D73.2 (A), MX71.2 (ROW)
unnamed: D74.2 (A), MX72.2 (ROW)
unnamed: D75.2 (A), MX73.2 (ROW)
unnamed: D76.2 (A), MX74.2 (ROW)
unnamed: D77.2 (A), MX75.2 (ROW)
unnamed: D78.2 (A), MX76.2 (ROW)
unnamed: D79.2 (A), MX77.2 (ROW)
unnamed: D80.2 (A), MX78.2 (ROW)
unnamed: D81.2 (A), MX79.2 (ROW)
unnamed: D82.2 (A), MX80.2 (ROW)
unnamed: D83.2 (A), MX81.2 (ROW)
unnamed: D84.2 (A), MX82.2 (ROW)
unnamed: D85.2 (A), MX83.2 (ROW)
unnamed: D86.2 (A), MX86.2 (ROW)
unnamed: D87.2 (A), MX89.2 (ROW)

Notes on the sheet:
1.25u LShift
Split Backspace
ISO Enter
ISO 1u

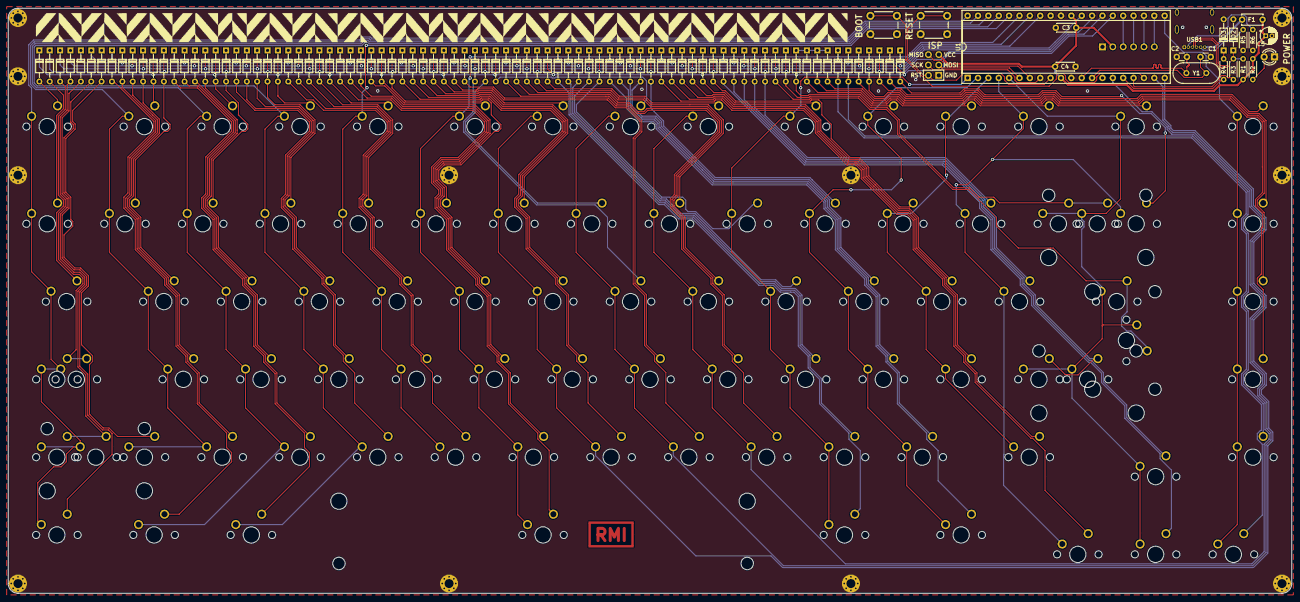
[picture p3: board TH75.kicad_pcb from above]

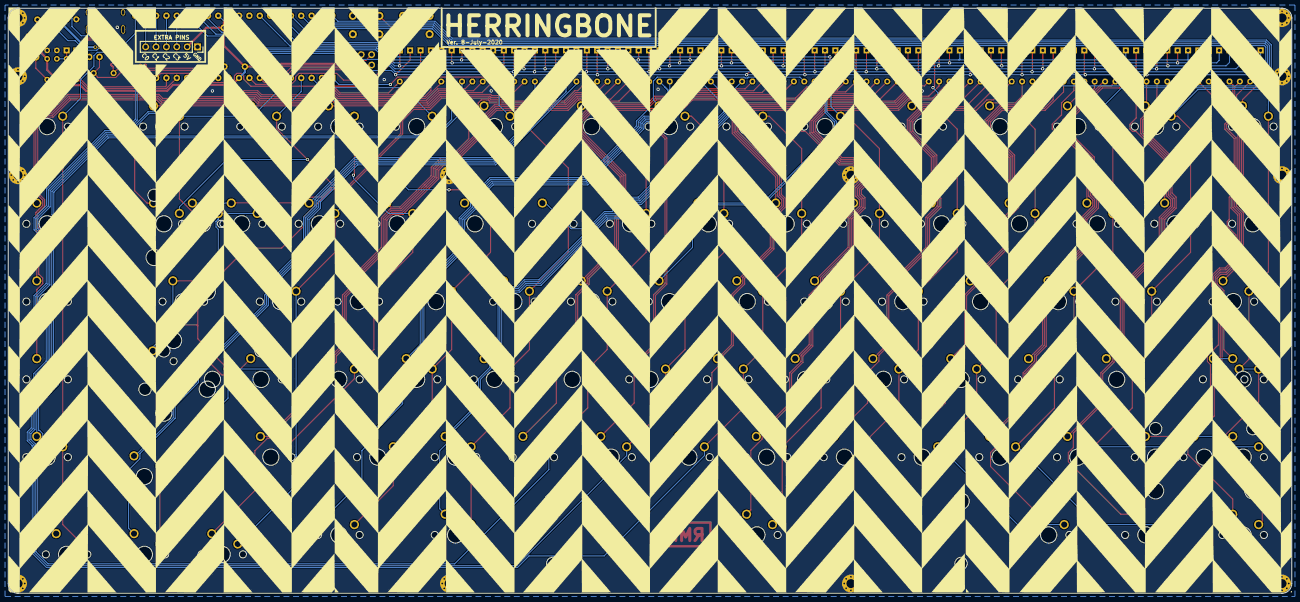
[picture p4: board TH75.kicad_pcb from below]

Board: 2 copper layers, 314.3 x 143.3 mm, 210 parts (2 on the bottom side), 126 nets.
